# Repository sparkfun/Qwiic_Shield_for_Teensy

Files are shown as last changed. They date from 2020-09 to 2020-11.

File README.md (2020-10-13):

SparkFun Qwiic Shield for Teensy 
========================================

SparkFun Qwiic Shield for Teensy

[SparkFun Qwiic Shield for Teensy (DEV-17119)](https://www.sparkfun.com/products/17119)

The SparkFun Qwiic Shield for Teensy connects the I<sup>2</sup>C bus on a Teensy footprint (Teensy 4, 3.2, LC) to four Qwiic connectors as well as a "PROG" button in parallel with the Program button on the Teensy development board for easy access. The shield comes with the [Teensy Header Kit](https://www.sparkfun.com/products/13925) to solder to the shield for connection to the Teensy.

Repository Contents
-------------------

* **/Documentation** - Board schematic (PDF) and dimensions (PNG & PDF)
* **/Hardware** - Eagle design files (.brd, .sch)

Documentation
--------------
* **[Hookup Guide](https://learn.sparkfun.com/tutorials/sparkfun-qwiic-shield-for-teensy-hookup-guide)** - Basic hookup guide for the SparkFun Qwiic Shield for Teensy

Version History
---------------
* **[DEV-17119](https://www.sparkfun.com/products/17119)** - Initial release.

License Information
-------------------

This product is _**open source**_! 

Please review the LICENSE.md file for license information. 

If you have any questions or concerns on licensing, please contact technical support on our [SparkFun forums](https://forum.sparkfun.com/viewforum.php?f=152).

Distributed as-is; no warranty is given.

- Your friends at SparkFun.

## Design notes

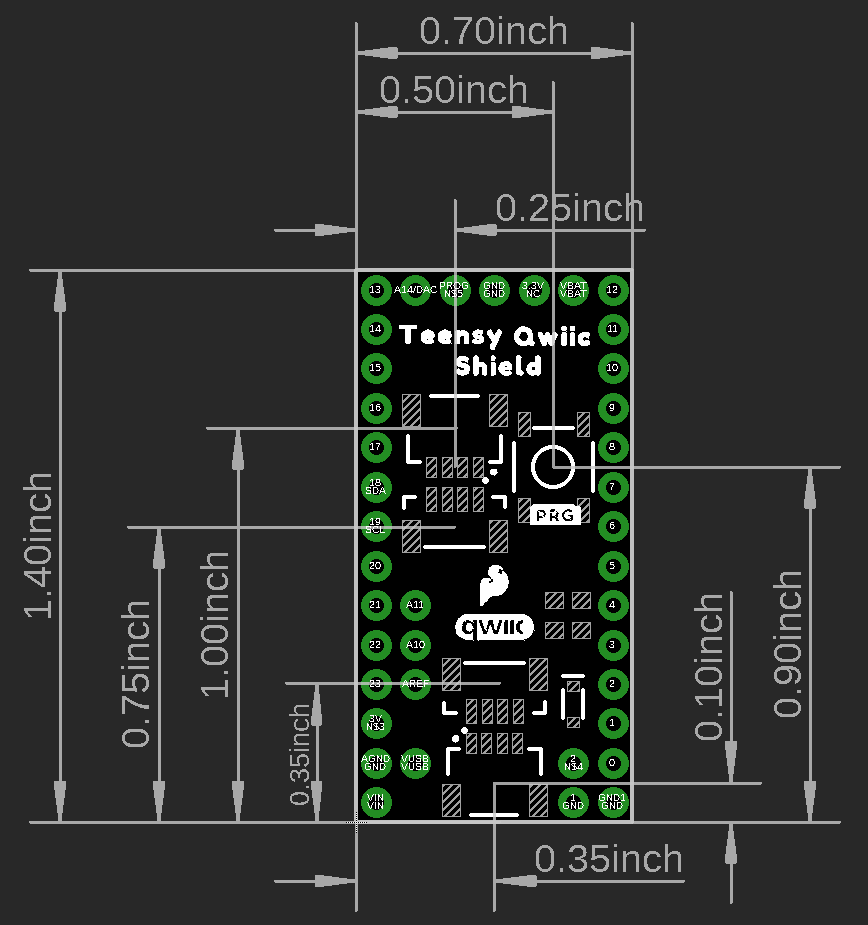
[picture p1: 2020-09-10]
Documents/Qwiic_Shield_for_Teensy_Dimensions.png

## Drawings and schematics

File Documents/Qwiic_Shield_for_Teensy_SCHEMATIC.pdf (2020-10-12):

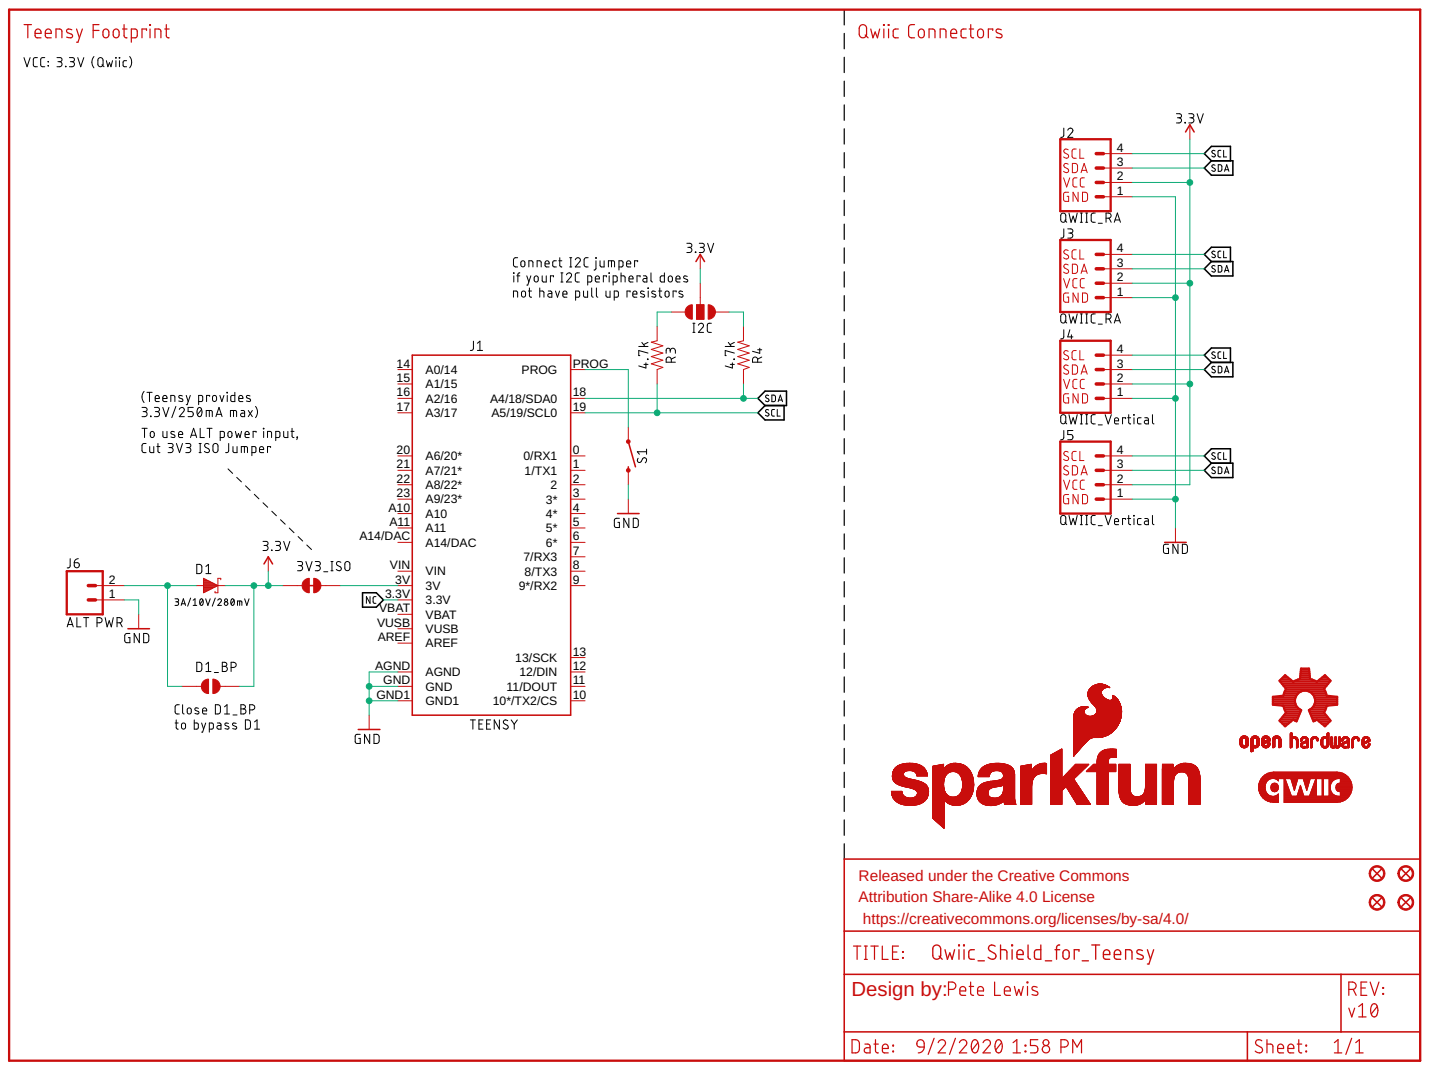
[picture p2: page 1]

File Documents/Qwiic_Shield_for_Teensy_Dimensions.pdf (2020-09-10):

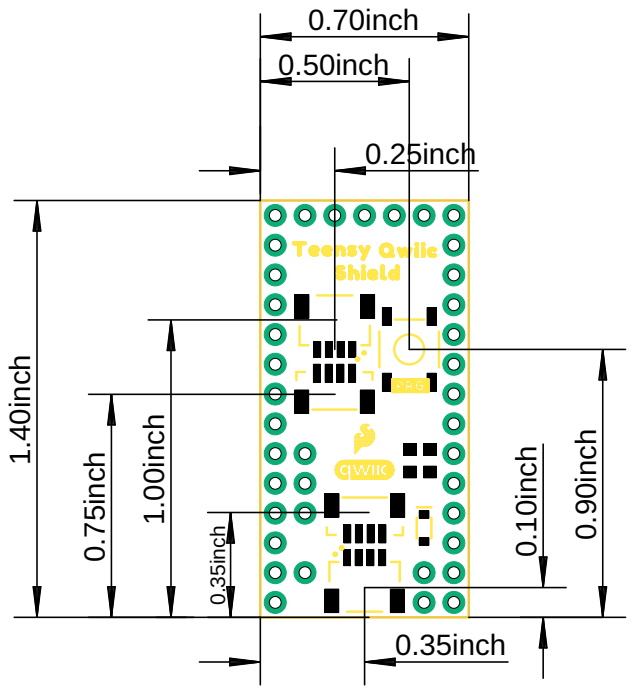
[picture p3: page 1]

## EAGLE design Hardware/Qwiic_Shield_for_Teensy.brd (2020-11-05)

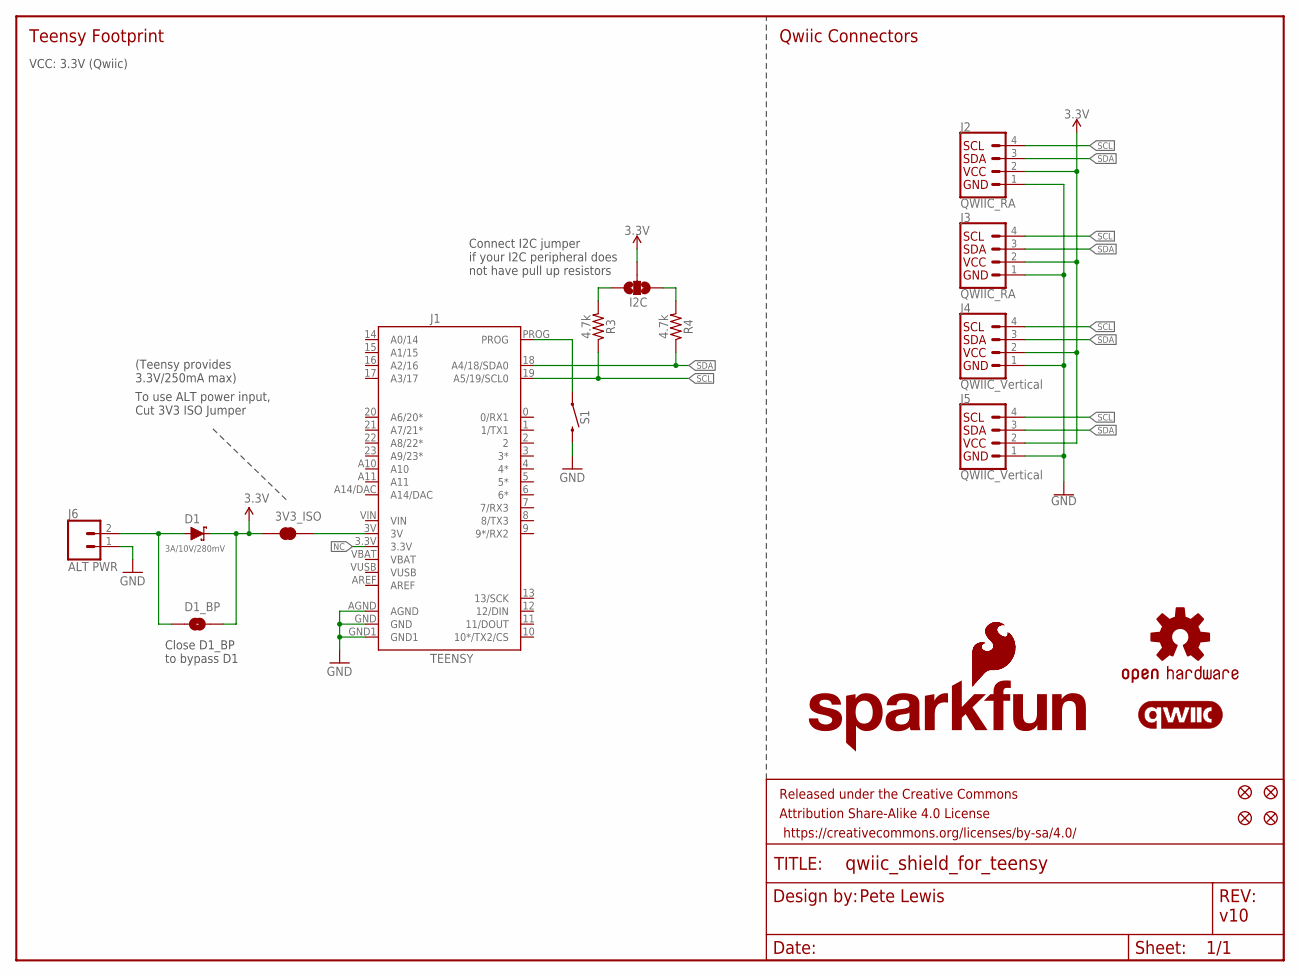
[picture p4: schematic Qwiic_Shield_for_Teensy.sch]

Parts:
3V3_ISO: JUMPER-SMT_2_NC_TRACE_SILK; SMT-JUMPER_2_NC_TRACE_SILK
D1: 3A/10V/280mV; SOD-323
D1_BP: JUMPER-SMT_2_NO_SILK; SMT-JUMPER_2_NO_SILK
FD1, FD2, FD3, FD4: FIDUCIAL1X2; FIDUCIAL-1X2
FRAME1: FRAME-LETTER; CREATIVE_COMMONS
I2C: JUMPER-SMT_3_NO_SILK; SMT-JUMPER_3_NO_SILK
J1: TEENSY; TEENSY_NOSILK
J2, J3: QWIIC_RA; JST04_1MM_RA
J4, J5: QWIIC_Vertical; JST04_1MM_VERT
J6: ALT PWR; 1X02_NO_SILK
LOGO1: SFE_LOGO_NAME_FLAME.1_INCH; SFE_LOGO_NAME_FLAME_.1
LOGO2: SFE_LOGO_FLAME.1_INCH; SFE_LOGO_FLAME_.1
LOGO3: OSHW-LOGOS; OSHW-LOGO-S
LOGO4: QWIIC_LOGO_5MM; QWIIC_5MM
R3, R4: 4.7k; 0603
S1: SMD_5.2MM; TACTILE_SWITCH_SMD_5.2MM

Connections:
3.3V: 3V3_ISO.1, D1.C, D1_BP.2, I2C.2, J2.2, J3.2, J4.2, J5.2
GND: J1.AGND, J1.GND, J1.GND1, J2.1, J3.1, J4.1, J5.1, J6.1, S1.3 (2)
unnamed: I2C.3, R4.2
unnamed: I2C.1, R3.2
unnamed: 3V3_ISO.2, J1.3V
unnamed: D1.A, D1_BP.1, J6.2
unnamed: J1.PROG, S1.1
NC: J1.3.3V
SCL: J1.19 (A5/19/SCL0), J2.4, J3.4, J4.4, J5.4, R3.1
SDA: J1.18 (A4/18/SDA0), J2.3, J3.3, J4.3, J5.3, R4.1
VBAT: J1.VBAT
VIN: J1.VIN
VUSB: J1.VUSB

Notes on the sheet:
Pete Lewis
v10
Teensy Footprint
Qwiic Connectors
VCC: 3.3V (Qwiic)
(Teensy provides 3.3V/250mA max)
Connect I2C jumper if your I2C peripheral does not have pull up resistors
To use ALT power input, Cut 3V3 ISO Jumper
Close D1_BP to bypass D1

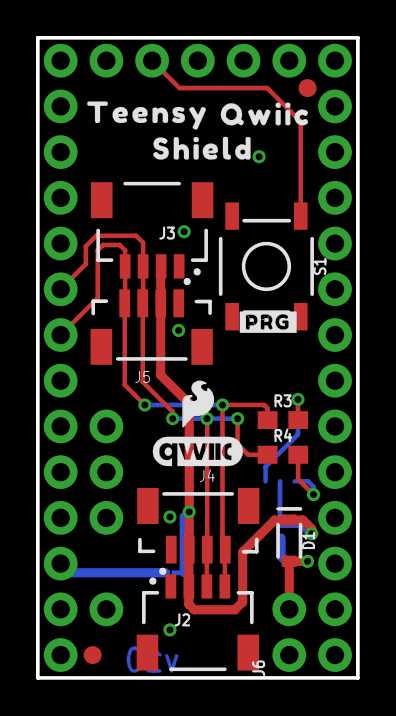
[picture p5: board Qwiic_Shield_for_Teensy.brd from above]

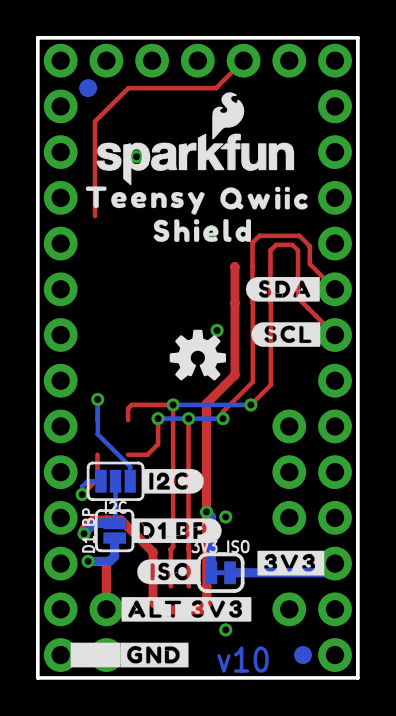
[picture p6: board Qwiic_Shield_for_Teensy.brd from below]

Board: 2 copper layers, 17.8 x 35.6 mm, 38 parts (18 on the bottom side), 9 nets.

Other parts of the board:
U$1: #I2C#0
U$2, U$13: TEENSY0
U$3: 3V36
U$4: #D1_BP#0
U$5: #ALT_3V3#0
U$6: #PRG#0
U$7: #GND#0
U$8, U$12: SHIELD0
U$9, U$11: QWIIC0
U$10: #ISO#0
U$15: #3V3#0
U$18: #SDA#0
U$19: #SCL#0

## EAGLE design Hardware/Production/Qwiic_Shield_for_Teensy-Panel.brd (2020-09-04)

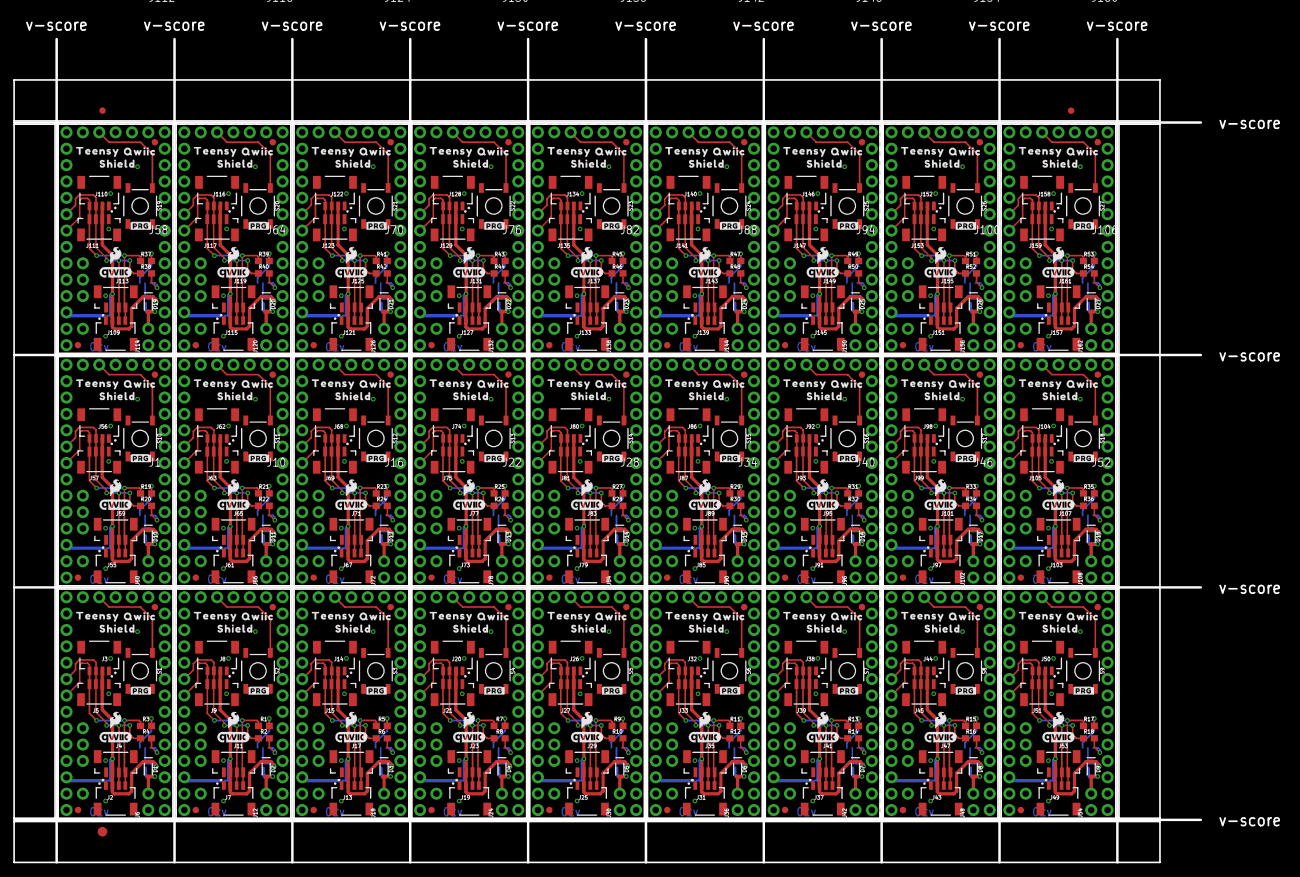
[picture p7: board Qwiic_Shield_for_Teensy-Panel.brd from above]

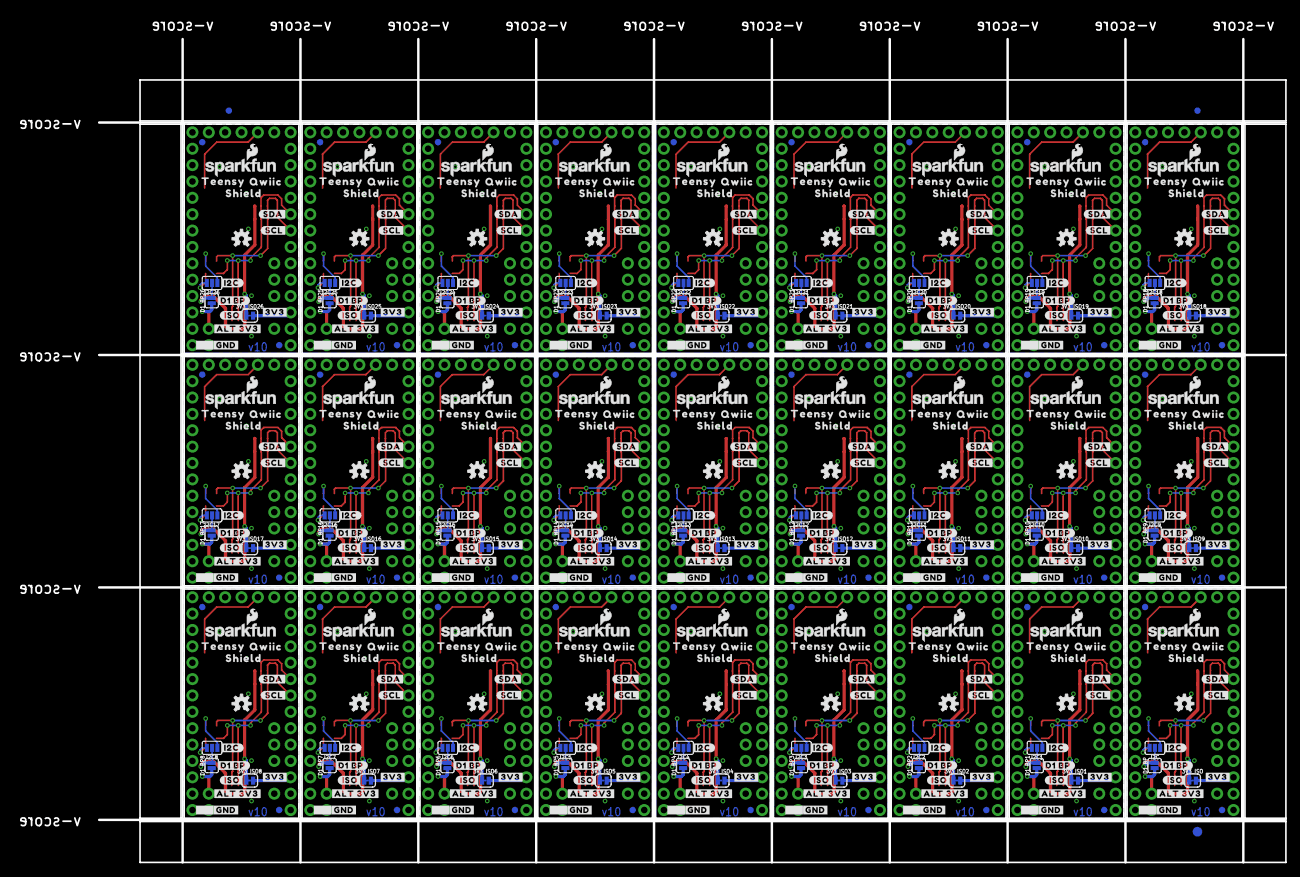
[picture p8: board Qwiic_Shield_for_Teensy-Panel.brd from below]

Board: 2 copper layers, 184.2 x 127.8 mm, 1005 parts (489 on the bottom side), 243 nets.

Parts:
3V3_ISO, 3V3_ISO1, 3V3_ISO2, 3V3_ISO3, 3V3_ISO4, 3V3_ISO5, 3V3_ISO6, 3V3_ISO7, 3V3_ISO8, 3V3_ISO9, 3V3_ISO10, 3V3_ISO11, 3V3_ISO12, 3V3_ISO13, 3V3_ISO14, 3V3_ISO15, 3V3_ISO16, 3V3_ISO17, 3V3_ISO18, 3V3_ISO19, 3V3_ISO20, 3V3_ISO21, 3V3_ISO22, 3V3_ISO23, 3V3_ISO24, 3V3_ISO25, 3V3_ISO26: SMT-JUMPER_2_NC_TRACE_SILK
D1, D2, D3, D4, D5, D6, D7, D8, D9, D10, D11, D12, D13, D14, D15, D16, D17, D18, D19, D20, D21, D22, D23, D24, D25, D26, D27: 3A/10V/280mV; SOD-323
D1_BP, D1_BP1, D1_BP2, D1_BP3, D1_BP4, D1_BP5, D1_BP6, D1_BP7, D1_BP8, D1_BP9, D1_BP10, D1_BP11, D1_BP12, D1_BP13, D1_BP14, D1_BP15, D1_BP16, D1_BP17, D1_BP18, D1_BP19, D1_BP20, D1_BP21, D1_BP22, D1_BP23, D1_BP24, D1_BP25, D1_BP26: SMT-JUMPER_2_NO_SILK
E$1, E$2, E$3, E$4: FIDUCIAL-1X2
E$5, E$6: FIDUCIAL-1.5X3
FD1, FD2, FD3, FD4, FD5, FD6, FD7, FD8, FD9, FD10, FD11, FD12, FD13, FD14, FD15, FD16, FD17, FD18, FD19, FD20, FD21, FD22, FD23, FD24, FD25, FD26, FD27, FD28, FD29, FD30, FD31, FD32, FD33, FD34, FD35, FD36, FD37, FD38, FD39, FD40, FD41, FD42, FD43, FD44, FD45, FD46, FD47, FD48, FD49, FD50, FD51, FD52, FD53, FD54, FD55, FD56, FD57, FD58, FD59, FD60, FD61, FD62, FD63, FD64, FD65, FD66, FD67, FD68, FD69, FD70, FD71, FD72, FD73, FD74, FD75, FD76, FD77, FD78, FD79, FD80, FD81, FD82, FD83, FD84, FD85, FD86, FD87, FD88, FD89, FD90, FD91, FD92, FD93, FD94, FD95, FD96, FD97, FD98, FD99, FD100, FD101, FD102, FD103, FD104, FD105, FD106, FD107, FD108: FIDUCIAL1X2; FIDUCIAL-1X2
I2C, I2C1, I2C2, I2C3, I2C4, I2C5, I2C6, I2C7, I2C8, I2C9, I2C10, I2C11, I2C12, I2C13, I2C14, I2C15, I2C16, I2C17, I2C18, I2C19, I2C20, I2C21, I2C22, I2C23, I2C24, I2C25, I2C26: JUMPER-SMT_3_NO_SILK; SMT-JUMPER_3_NO_SILK
J1, J10, J16, J22, J28, J34, J40, J46, J52, J58, J64, J70, J76, J82, J88, J94, J100, J106, J112, J118, J124, J130, J136, J142, J148, J154, J160: TEENSY; TEENSY_NOSILK
J2, J3, J7, J8, J13, J14, J19, J20, J25, J26, J31, J32, J37, J38, J43, J44, J49, J50, J55, J56, J61, J62, J67, J68, J73, J74, J79, J80, J85, J86, J91, J92, J97, J98, J103, J104, J109, J110, J115, J116, J121, J122, J127, J128, J133, J134, J139, J140, J145, J146, J151, J152, J157, J158: QWIIC_RA; JST04_1MM_RA
J4, J5, J9, J11, J15, J17, J21, J23, J27, J29, J33, J35, J39, J41, J45, J47, J51, J53, J57, J59, J63, J65, J69, J71, J75, J77, J81, J83, J87, J89, J93, J95, J99, J101, J105, J107, J111, J113, J117, J119, J123, J125, J129, J131, J135, J137, J141, J143, J147, J149, J153, J155, J159, J161: QWIIC_Vertical; JST04_1MM_VERT
J6, J12, J18, J24, J30, J36, J42, J48, J54, J60, J66, J72, J78, J84, J90, J96, J102, J108, J114, J120, J126, J132, J138, J144, J150, J156, J162: ALT PWR; 1X02_NO_SILK
LOGO1, LOGO5, LOGO9, LOGO13, LOGO17, LOGO21, LOGO25, LOGO29, LOGO33, LOGO37, LOGO41, LOGO45, LOGO49, LOGO53, LOGO57, LOGO61, LOGO65, LOGO69, LOGO73, LOGO77, LOGO81, LOGO85, LOGO89, LOGO93, LOGO97, LOGO101, LOGO105: SFE_LOGO_NAME_FLAME.1_INCH; SFE_LOGO_NAME_FLAME_.1
LOGO2, LOGO8, LOGO12, LOGO16, LOGO20, LOGO24, LOGO28, LOGO32, LOGO36, LOGO40, LOGO44, LOGO48, LOGO52, LOGO56, LOGO60, LOGO64, LOGO68, LOGO72, LOGO76, LOGO80, LOGO84, LOGO88, LOGO92, LOGO96, LOGO100, LOGO104, LOGO108: SFE_LOGO_FLAME.1_INCH; SFE_LOGO_FLAME_.1
LOGO3, LOGO6, LOGO10, LOGO14, LOGO18, LOGO22, LOGO26, LOGO30, LOGO34, LOGO38, LOGO42, LOGO46, LOGO50, LOGO54, LOGO58, LOGO62, LOGO66, LOGO70, LOGO74, LOGO78, LOGO82, LOGO86, LOGO90, LOGO94, LOGO98, LOGO102, LOGO106: OSHW-LOGOS; OSHW-LOGO-S
LOGO4, LOGO7, LOGO11, LOGO15, LOGO19, LOGO23, LOGO27, LOGO31, LOGO35, LOGO39, LOGO43, LOGO47, LOGO51, LOGO55, LOGO59, LOGO63, LOGO67, LOGO71, LOGO75, LOGO79, LOGO83, LOGO87, LOGO91, LOGO95, LOGO99, LOGO103, LOGO107: QWIIC_LOGO_5MM; QWIIC_5MM
R1, R2, R3, R4, R5, R6, R7, R8, R9, R10, R11, R12, R13, R14, R15, R16, R17, R18, R19, R20, R21, R22, R23, R24, R25, R26, R27, R28, R29, R30, R31, R32, R33, R34, R35, R36, R37, R38, R39, R40, R41, R42, R43, R44, R45, R46, R47, R48, R49, R50, R51, R52, R53, R54: 4.7k; 0603
S1, S2, S3, S4, S5, S6, S7, S8, S9, S10, S11, S12, S13, S14, S15, S16, S17, S18, S19, S20, S21, S22, S23, S24, S25, S26, S27: SMD_5.2MM; TACTILE_SWITCH_SMD_5.2MM
U$1, U$22, U$38, U$54, U$70, U$86, U$102, U$118, U$134, U$150, U$166, U$182, U$198, U$214, U$230, U$246, U$262, U$278, U$294, U$310, U$326, U$342, U$358, U$374, U$390, U$406, U$422: #I2C#0
U$2, U$13, U$16, U$30, U$34, U$46, U$50, U$62, U$66, U$78, U$82, U$94, U$98, U$110, U$114, U$126, U$130, U$142, U$146, U$158, U$162, U$174, U$178, U$190, U$194, U$206, U$210, U$222, U$226, U$238, U$242, U$254, U$258, U$270, U$274, U$286, U$290, U$302, U$306, U$318, U$322, U$334, U$338, U$350, U$354, U$366, U$370, U$382, U$386, U$398, U$402, U$414, U$418, U$430: TEENSY0
U$3, U$14, U$33, U$49, U$65, U$81, U$97, U$113, U$129, U$145, U$161, U$177, U$193, U$209, U$225, U$241, U$257, U$273, U$289, U$305, U$321, U$337, U$353, U$369, U$385, U$401, U$417: 3V36
U$4, U$23, U$39, U$55, U$71, U$87, U$103, U$119, U$135, U$151, U$167, U$183, U$199, U$215, U$231, U$247, U$263, U$279, U$295, U$311, U$327, U$343, U$359, U$375, U$391, U$407, U$423: #D1_BP#0
U$5, U$24, U$40, U$56, U$72, U$88, U$104, U$120, U$136, U$152, U$168, U$184, U$200, U$216, U$232, U$248, U$264, U$280, U$296, U$312, U$328, U$344, U$360, U$376, U$392, U$408, U$424: #ALT_3V3#0
U$6, U$28, U$44, U$60, U$76, U$92, U$108, U$124, U$140, U$156, U$172, U$188, U$204, U$220, U$236, U$252, U$268, U$284, U$300, U$316, U$332, U$348, U$364, U$380, U$396, U$412, U$428: #PRG#0
U$7, U$25, U$41, U$57, U$73, U$89, U$105, U$121, U$137, U$153, U$169, U$185, U$201, U$217, U$233, U$249, U$265, U$281, U$297, U$313, U$329, U$345, U$361, U$377, U$393, U$409, U$425: #GND#0
U$8, U$12, U$26, U$32, U$42, U$48, U$58, U$64, U$74, U$80, U$90, U$96, U$106, U$112, U$122, U$128, U$138, U$144, U$154, U$160, U$170, U$176, U$186, U$192, U$202, U$208, U$218, U$224, U$234, U$240, U$250, U$256, U$266, U$272, U$282, U$288, U$298, U$304, U$314, U$320, U$330, U$336, U$346, U$352, U$362, U$368, U$378, U$384, U$394, U$400, U$410, U$416, U$426, U$432: SHIELD0
U$9, U$11, U$27, U$31, U$43, U$47, U$59, U$63, U$75, U$79, U$91, U$95, U$107, U$111, U$123, U$127, U$139, U$143, U$155, U$159, U$171, U$175, U$187, U$191, U$203, U$207, U$219, U$223, U$235, U$239, U$251, U$255, U$267, U$271, U$283, U$287, U$299, U$303, U$315, U$319, U$331, U$335, U$347, U$351, U$363, U$367, U$379, U$383, U$395, U$399, U$411, U$415, U$427, U$431: QWIIC0
U$10, U$29, U$45, U$61, U$77, U$93, U$109, U$125, U$141, U$157, U$173, U$189, U$205, U$221, U$237, U$253, U$269, U$285, U$301, U$317, U$333, U$349, U$365, U$381, U$397, U$413, U$429: #ISO#0
U$15, U$17, U$35, U$51, U$67, U$83, U$99, U$115, U$131, U$147, U$163, U$179, U$195, U$211, U$227, U$243, U$259, U$275, U$291, U$307, U$323, U$339, U$355, U$371, U$387, U$403, U$419: #3V3#0
U$18, U$20, U$36, U$52, U$68, U$84, U$100, U$116, U$132, U$148, U$164, U$180, U$196, U$212, U$228, U$244, U$260, U$276, U$292, U$308, U$324, U$340, U$356, U$372, U$388, U$404, U$420: #SDA#0
U$19, U$21, U$37, U$53, U$69, U$85, U$101, U$117, U$133, U$149, U$165, U$181, U$197, U$213, U$229, U$245, U$261, U$277, U$293, U$309, U$325, U$341, U$357, U$373, U$389, U$405, U$421: #SCL#0

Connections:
3.3V: 3V3_ISO.1, D1.C, D1_BP.2, I2C.2, J2.2, J3.2, J4.2, J5.2
3.3V1: 3V3_ISO1.1, D1_BP1.2, D2.C, I2C1.2, J7.2, J8.2, J9.2, J11.2
3.3V2: 3V3_ISO2.1, D1_BP2.2, D3.C, I2C2.2, J13.2, J14.2, J15.2, J17.2
3.3V3: 3V3_ISO3.1, D1_BP3.2, D4.C, I2C3.2, J19.2, J20.2, J21.2, J23.2
3.3V4: 3V3_ISO4.1, D1_BP4.2, D5.C, I2C4.2, J25.2, J26.2, J27.2, J29.2
3.3V5: 3V3_ISO5.1, D1_BP5.2, D6.C, I2C5.2, J31.2, J32.2, J33.2, J35.2
3.3V6: 3V3_ISO6.1, D1_BP6.2, D7.C, I2C6.2, J37.2, J38.2, J39.2, J41.2
3.3V7: 3V3_ISO7.1, D1_BP7.2, D8.C, I2C7.2, J43.2, J44.2, J45.2, J47.2
3.3V8: 3V3_ISO8.1, D1_BP8.2, D9.C, I2C8.2, J49.2, J50.2, J51.2, J53.2
3.3V9: 3V3_ISO9.1, D1_BP9.2, D10.C, I2C9.2, J55.2, J56.2, J57.2, J59.2
3.3V10: 3V3_ISO10.1, D1_BP10.2, D11.C, I2C10.2, J61.2, J62.2, J63.2, J65.2
3.3V11: 3V3_ISO11.1, D1_BP11.2, D12.C, I2C11.2, J67.2, J68.2, J69.2, J71.2
3.3V12: 3V3_ISO12.1, D1_BP12.2, D13.C, I2C12.2, J73.2, J74.2, J75.2, J77.2
3.3V13: 3V3_ISO13.1, D1_BP13.2, D14.C, I2C13.2, J79.2, J80.2, J81.2, J83.2
3.3V14: 3V3_ISO14.1, D1_BP14.2, D15.C, I2C14.2, J85.2, J86.2, J87.2, J89.2
3.3V15: 3V3_ISO15.1, D1_BP15.2, D16.C, I2C15.2, J91.2, J92.2, J93.2, J95.2
3.3V16: 3V3_ISO16.1, D1_BP16.2, D17.C, I2C16.2, J97.2, J98.2, J99.2, J101.2
3.3V17: 3V3_ISO17.1, D1_BP17.2, D18.C, I2C17.2, J103.2, J104.2, J105.2, J107.2
3.3V18: 3V3_ISO18.1, D1_BP18.2, D19.C, I2C18.2, J109.2, J110.2, J111.2, J113.2
3.3V19: 3V3_ISO19.1, D1_BP19.2, D20.C, I2C19.2, J115.2, J116.2, J117.2, J119.2
3.3V20: 3V3_ISO20.1, D1_BP20.2, D21.C, I2C20.2, J121.2, J122.2, J123.2, J125.2
3.3V21: 3V3_ISO21.1, D1_BP21.2, D22.C, I2C21.2, J127.2, J128.2, J129.2, J131.2
3.3V22: 3V3_ISO22.1, D1_BP22.2, D23.C, I2C22.2, J133.2, J134.2, J135.2, J137.2
3.3V23: 3V3_ISO23.1, D1_BP23.2, D24.C, I2C23.2, J139.2, J140.2, J141.2, J143.2
3.3V24: 3V3_ISO24.1, D1_BP24.2, D25.C, I2C24.2, J145.2, J146.2, J147.2, J149.2
3.3V25: 3V3_ISO25.1, D1_BP25.2, D26.C, I2C25.2, J151.2, J152.2, J153.2, J155.2
3.3V26: 3V3_ISO26.1, D1_BP26.2, D27.C, I2C26.2, J157.2, J158.2, J159.2, J161.2
GND: J1.AGND, J1.GND, J1.GND1, J2.1, J3.1, J4.1, J5.1, J6.1, S1.3
GND1: J7.1, J8.1, J9.1, J10.AGND, J10.GND, J10.GND1, J11.1, J12.1, S2.3
GND2: J13.1, J14.1, J15.1, J16.AGND, J16.GND, J16.GND1, J17.1, J18.1, S3.3
GND3: J19.1, J20.1, J21.1, J22.AGND, J22.GND, J22.GND1, J23.1, J24.1, S4.3
GND4: J25.1, J26.1, J27.1, J28.AGND, J28.GND, J28.GND1, J29.1, J30.1, S5.3
GND5: J31.1, J32.1, J33.1, J34.AGND, J34.GND, J34.GND1, J35.1, J36.1, S6.3
GND6: J37.1, J38.1, J39.1, J40.AGND, J40.GND, J40.GND1, J41.1, J42.1, S7.3
GND7: J43.1, J44.1, J45.1, J46.AGND, J46.GND, J46.GND1, J47.1, J48.1, S8.3
GND8: J49.1, J50.1, J51.1, J52.AGND, J52.GND, J52.GND1, J53.1, J54.1, S9.3
GND9: J55.1, J56.1, J57.1, J58.AGND, J58.GND, J58.GND1, J59.1, J60.1, S10.3
GND10: J61.1, J62.1, J63.1, J64.AGND, J64.GND, J64.GND1, J65.1, J66.1, S11.3
GND11: J67.1, J68.1, J69.1, J70.AGND, J70.GND, J70.GND1, J71.1, J72.1, S12.3
GND12: J73.1, J74.1, J75.1, J76.AGND, J76.GND, J76.GND1, J77.1, J78.1, S13.3
GND13: J79.1, J80.1, J81.1, J82.AGND, J82.GND, J82.GND1, J83.1, J84.1, S14.3
GND14: J85.1, J86.1, J87.1, J88.AGND, J88.GND, J88.GND1, J89.1, J90.1, S15.3
GND15: J91.1, J92.1, J93.1, J94.AGND, J94.GND, J94.GND1, J95.1, J96.1, S16.3
GND16: J97.1, J98.1, J99.1, J100.AGND, J100.GND, J100.GND1, J101.1, J102.1, S17.3
GND17: J103.1, J104.1, J105.1, J106.AGND, J106.GND, J106.GND1, J107.1, J108.1, S18.3
GND18: J109.1, J110.1, J111.1, J112.AGND, J112.GND, J112.GND1, J113.1, J114.1, S19.3
GND19: J115.1, J116.1, J117.1, J118.AGND, J118.GND, J118.GND1, J119.1, J120.1, S20.3
GND20: J121.1, J122.1, J123.1, J124.AGND, J124.GND, J124.GND1, J125.1, J126.1, S21.3
GND21: J127.1, J128.1, J129.1, J130.AGND, J130.GND, J130.GND1, J131.1, J132.1, S22.3
GND22: J133.1, J134.1, J135.1, J136.AGND, J136.GND, J136.GND1, J137.1, J138.1, S23.3
GND23: J139.1, J140.1, J141.1, J142.AGND, J142.GND, J142.GND1, J143.1, J144.1, S24.3
GND24: J145.1, J146.1, J147.1, J148.AGND, J148.GND, J148.GND1, J149.1, J150.1, S25.3
GND25: J151.1, J152.1, J153.1, J154.AGND, J154.GND, J154.GND1, J155.1, J156.1, S26.3
GND26: J157.1, J158.1, J159.1, J160.AGND, J160.GND, J160.GND1, J161.1, J162.1, S27.3
unnamed: I2C.3, R4.2
unnamed: I2C.1, R3.2
unnamed: 3V3_ISO.2, J1.3V
unnamed: D1.A, D1_BP.1, J6.2
unnamed: J1.PROG, S1.1
unnamed: I2C1.3, R2.2
unnamed: I2C1.1, R1.2
unnamed: D1_BP1.1, D2.A, J12.2
unnamed: J10.PROG, S2.1
unnamed: 3V3_ISO1.2, J10.3V
unnamed: I2C2.3, R6.2
unnamed: I2C2.1, R5.2
unnamed: D1_BP2.1, D3.A, J18.2
unnamed: J16.PROG, S3.1
unnamed: 3V3_ISO2.2, J16.3V
unnamed: I2C3.3, R8.2
unnamed: I2C3.1, R7.2
unnamed: D1_BP3.1, D4.A, J24.2
unnamed: J22.PROG, S4.1
unnamed: 3V3_ISO3.2, J22.3V
unnamed: I2C4.3, R10.2
unnamed: I2C4.1, R9.2
unnamed: D1_BP4.1, D5.A, J30.2
unnamed: J28.PROG, S5.1
unnamed: 3V3_ISO4.2, J28.3V
unnamed: I2C5.3, R12.2
unnamed: I2C5.1, R11.2
unnamed: D1_BP5.1, D6.A, J36.2
unnamed: J34.PROG, S6.1
unnamed: 3V3_ISO5.2, J34.3V
unnamed: I2C6.3, R14.2
unnamed: I2C6.1, R13.2
unnamed: D1_BP6.1, D7.A, J42.2
unnamed: J40.PROG, S7.1
unnamed: 3V3_ISO6.2, J40.3V
unnamed: I2C7.3, R16.2
unnamed: I2C7.1, R15.2
unnamed: D1_BP7.1, D8.A, J48.2
unnamed: J46.PROG, S8.1
unnamed: 3V3_ISO7.2, J46.3V
unnamed: I2C8.3, R18.2
unnamed: I2C8.1, R17.2
unnamed: D1_BP8.1, D9.A, J54.2
unnamed: J52.PROG, S9.1
unnamed: 3V3_ISO8.2, J52.3V
unnamed: I2C9.3, R20.2
unnamed: I2C9.1, R19.2
unnamed: D1_BP9.1, D10.A, J60.2
unnamed: J58.PROG, S10.1
unnamed: 3V3_ISO9.2, J58.3V
unnamed: I2C10.3, R22.2
unnamed: I2C10.1, R21.2
unnamed: D1_BP10.1, D11.A, J66.2
unnamed: J64.PROG, S11.1
unnamed: 3V3_ISO10.2, J64.3V
unnamed: I2C11.3, R24.2
unnamed: I2C11.1, R23.2
unnamed: D1_BP11.1, D12.A, J72.2
unnamed: J70.PROG, S12.1
unnamed: 3V3_ISO11.2, J70.3V
unnamed: I2C12.3, R26.2
unnamed: I2C12.1, R25.2
unnamed: D1_BP12.1, D13.A, J78.2
unnamed: J76.PROG, S13.1
unnamed: 3V3_ISO12.2, J76.3V
unnamed: I2C13.3, R28.2
unnamed: I2C13.1, R27.2
unnamed: D1_BP13.1, D14.A, J84.2
unnamed: J82.PROG, S14.1
unnamed: 3V3_ISO13.2, J82.3V
unnamed: I2C14.3, R30.2
unnamed: I2C14.1, R29.2
unnamed: D1_BP14.1, D15.A, J90.2
unnamed: J88.PROG, S15.1
unnamed: 3V3_ISO14.2, J88.3V
unnamed: I2C15.3, R32.2
unnamed: I2C15.1, R31.2
unnamed: D1_BP15.1, D16.A, J96.2
unnamed: J94.PROG, S16.1
unnamed: 3V3_ISO15.2, J94.3V
unnamed: I2C16.3, R34.2
unnamed: I2C16.1, R33.2
unnamed: D1_BP16.1, D17.A, J102.2
unnamed: J100.PROG, S17.1
unnamed: 3V3_ISO16.2, J100.3V
unnamed: I2C17.3, R36.2
unnamed: I2C17.1, R35.2
unnamed: D1_BP17.1, D18.A, J108.2
unnamed: J106.PROG, S18.1
unnamed: 3V3_ISO17.2, J106.3V
unnamed: I2C18.3, R38.2
unnamed: I2C18.1, R37.2
unnamed: D1_BP18.1, D19.A, J114.2
unnamed: J112.PROG, S19.1
unnamed: 3V3_ISO18.2, J112.3V
unnamed: I2C19.3, R40.2
unnamed: I2C19.1, R39.2
unnamed: D1_BP19.1, D20.A, J120.2
unnamed: J118.PROG, S20.1
unnamed: 3V3_ISO19.2, J118.3V
unnamed: I2C20.3, R42.2
unnamed: I2C20.1, R41.2
unnamed: D1_BP20.1, D21.A, J126.2
unnamed: J124.PROG, S21.1
unnamed: 3V3_ISO20.2, J124.3V
unnamed: I2C21.3, R44.2
unnamed: I2C21.1, R43.2
unnamed: D1_BP21.1, D22.A, J132.2
unnamed: J130.PROG, S22.1
unnamed: 3V3_ISO21.2, J130.3V
unnamed: I2C22.3, R46.2
unnamed: I2C22.1, R45.2
unnamed: D1_BP22.1, D23.A, J138.2
unnamed: J136.PROG, S23.1
unnamed: 3V3_ISO22.2, J136.3V
unnamed: I2C23.3, R48.2
unnamed: I2C23.1, R47.2
unnamed: D1_BP23.1, D24.A, J144.2
unnamed: J142.PROG, S24.1
unnamed: 3V3_ISO23.2, J142.3V
unnamed: I2C24.3, R50.2
unnamed: I2C24.1, R49.2
unnamed: D1_BP24.1, D25.A, J150.2
unnamed: J148.PROG, S25.1
unnamed: 3V3_ISO24.2, J148.3V
unnamed: I2C25.3, R52.2
unnamed: I2C25.1, R51.2
unnamed: D1_BP25.1, D26.A, J156.2
unnamed: J154.PROG, S26.1
unnamed: 3V3_ISO25.2, J154.3V
unnamed: I2C26.3, R54.2
unnamed: I2C26.1, R53.2
unnamed: D1_BP26.1, D27.A, J162.2
unnamed: J160.PROG, S27.1
unnamed: 3V3_ISO26.2, J160.3V
SCL: J1.19, J2.4, J3.4, J4.4, J5.4, R3.1
SCL1: J7.4, J8.4, J9.4, J10.19, J11.4, R1.1
SCL2: J13.4, J14.4, J15.4, J16.19, J17.4, R5.1
SCL3: J19.4, J20.4, J21.4, J22.19, J23.4, R7.1
SCL4: J25.4, J26.4, J27.4, J28.19, J29.4, R9.1
SCL5: J31.4, J32.4, J33.4, J34.19, J35.4, R11.1
SCL6: J37.4, J38.4, J39.4, J40.19, J41.4, R13.1
SCL7: J43.4, J44.4, J45.4, J46.19, J47.4, R15.1
SCL8: J49.4, J50.4, J51.4, J52.19, J53.4, R17.1
SCL9: J55.4, J56.4, J57.4, J58.19, J59.4, R19.1
SCL10: J61.4, J62.4, J63.4, J64.19, J65.4, R21.1
SCL11: J67.4, J68.4, J69.4, J70.19, J71.4, R23.1
SCL12: J73.4, J74.4, J75.4, J76.19, J77.4, R25.1
SCL13: J79.4, J80.4, J81.4, J82.19, J83.4, R27.1
SCL14: J85.4, J86.4, J87.4, J88.19, J89.4, R29.1
SCL15: J91.4, J92.4, J93.4, J94.19, J95.4, R31.1
SCL16: J97.4, J98.4, J99.4, J100.19, J101.4, R33.1
SCL17: J103.4, J104.4, J105.4, J106.19, J107.4, R35.1
SCL18: J109.4, J110.4, J111.4, J112.19, J113.4, R37.1
SCL19: J115.4, J116.4, J117.4, J118.19, J119.4, R39.1
SCL20: J121.4, J122.4, J123.4, J124.19, J125.4, R41.1
SCL21: J127.4, J128.4, J129.4, J130.19, J131.4, R43.1
SCL22: J133.4, J134.4, J135.4, J136.19, J137.4, R45.1
SCL23: J139.4, J140.4, J141.4, J142.19, J143.4, R47.1
SCL24: J145.4, J146.4, J147.4, J148.19, J149.4, R49.1
SCL25: J151.4, J152.4, J153.4, J154.19, J155.4, R51.1
SCL26: J157.4, J158.4, J159.4, J160.19, J161.4, R53.1
SDA: J1.18, J2.3, J3.3, J4.3, J5.3, R4.1
SDA1: J7.3, J8.3, J9.3, J10.18, J11.3, R2.1
SDA2: J13.3, J14.3, J15.3, J16.18, J17.3, R6.1
SDA3: J19.3, J20.3, J21.3, J22.18, J23.3, R8.1
SDA4: J25.3, J26.3, J27.3, J28.18, J29.3, R10.1
SDA5: J31.3, J32.3, J33.3, J34.18, J35.3, R12.1
SDA6: J37.3, J38.3, J39.3, J40.18, J41.3, R14.1
SDA7: J43.3, J44.3, J45.3, J46.18, J47.3, R16.1
SDA8: J49.3, J50.3, J51.3, J52.18, J53.3, R18.1
SDA9: J55.3, J56.3, J57.3, J58.18, J59.3, R20.1
SDA10: J61.3, J62.3, J63.3, J64.18, J65.3, R22.1
SDA11: J67.3, J68.3, J69.3, J70.18, J71.3, R24.1
SDA12: J73.3, J74.3, J75.3, J76.18, J77.3, R26.1
SDA13: J79.3, J80.3, J81.3, J82.18, J83.3, R28.1
SDA14: J85.3, J86.3, J87.3, J88.18, J89.3, R30.1
SDA15: J91.3, J92.3, J93.3, J94.18, J95.3, R32.1
SDA16: J97.3, J98.3, J99.3, J100.18, J101.3, R34.1
SDA17: J103.3, J104.3, J105.3, J106.18, J107.3, R36.1
SDA18: J109.3, J110.3, J111.3, J112.18, J113.3, R38.1
SDA19: J115.3, J116.3, J117.3, J118.18, J119.3, R40.1
SDA20: J121.3, J122.3, J123.3, J124.18, J125.3, R42.1
SDA21: J127.3, J128.3, J129.3, J130.18, J131.3, R44.1
SDA22: J133.3, J134.3, J135.3, J136.18, J137.3, R46.1
SDA23: J139.3, J140.3, J141.3, J142.18, J143.3, R48.1
SDA24: J145.3, J146.3, J147.3, J148.18, J149.3, R50.1
SDA25: J151.3, J152.3, J153.3, J154.18, J155.3, R52.1
SDA26: J157.3, J158.3, J159.3, J160.18, J161.3, R54.1

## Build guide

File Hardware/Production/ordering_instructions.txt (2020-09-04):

panel size, 178x115mm
PCB thickness, 1.6mm
number of layers, 2
soldermask color, Red
silkscreen color, White
oz copper, 1oz
finish, HASL lead free
stencils, top
pcs per panel, 27
min trace width, 0.2540mm / 0.0100in
min drill size, 0.3810mm / 0.0150in

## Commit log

2020-08-20 ready for routing
    [Qwiic_Shield_for_Teensy.brd, Qwiic_Shield_for_Teensy.sch]
2020-08-24 Routing done
    -added diode on ALT 3V3 input
    -added PRG button for easier access to programming button
    -added prototyping area (with vscore) to extend this to also fit longer teensy board form factors
    [Qwiic_Shield_for_Teensy.brd, Qwiic_Shield_for_Teensy.sch]
2020-08-24 fixed tiny airwire
    [Qwiic_Shield_for_Teensy.brd]
2020-08-24 added measures
    [Qwiic_Shield_for_Teensy.brd]
2020-08-24 Teensy FP library update
    [Qwiic_Shield_for_Teensy.brd, Qwiic_Shield_for_Teensy.sch]
2020-08-25 DRC approvals, label adjustments
    -bumped GND pour isolates to 0.008 inch. This allows AREF pin to still get flowed gnd.
    -approved DRC errors about dimension on vscore line
    -fixed some angled traces.
    -removed some trace stubs
    -rotated SDA and SCL to match orientation of other labels
    -ensures all labels were size 0.04
    [Qwiic_Shield_for_Teensy.brd]
2020-08-25 checklist run pre group review
    -sch fonts to vector
    -via nudges to clear silk
    [Qwiic_Shield_for_Teensy.brd, Qwiic_Shield_for_Teensy.sch]
2020-08-31 Post group review changes - short version
    -"slave" terminology needs to be updated to "I2C peripheral"
    -Moving to two separate products. One short and one long. Resolves the prog button access pin difference. no vscores.
    -Switch up qwiic connector positions so that the north RA connector doesn't conflict with the prog button.
    -3.3V power should come from the PTH header pin on the side (not the middle row).
    -Added teensy qwiic shield product name to bottom silk
    [Qwiic_Shield_for_Teensy.brd, Qwiic_Shield_for_Teensy.sch]
2020-08-31 teensy long started
    library work and part placement mostly done. ready for routing.
    [Qwiic_Shield_for_Teensy_Long.brd, Qwiic_Shield_for_Teensy_Long.sch]
2020-09-01 Long version routed
    [Qwiic_Shield_for_Teensy_Long.brd, Qwiic_Shield_for_Teensy_Long.sch]
2020-09-01 Moving to "extended" product name
    -Eagle file name change (and sub-folder)
    -added silk to extended version
    [Qwiic_Shield_for_Teensy_Extended.brd, Qwiic_Shield_for_Teensy_Extended.sch]
2020-09-02 Library updates, name prefix fix, measures update
    [Qwiic_Shield_for_Teensy.brd, Qwiic_Shield_for_Teensy.sch, Qwiic_Shield_for_Teensy_Extended.brd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]
2020-09-02 separating repo into "normal" and extended versions
    [Qwiic_Shield_for_Teensy_Extended.brd, Qwiic_Shield_for_Teensy_Extended.sch]
2020-09-02 checklist run post design review
    -approved DRC overlap and clearance errors.
    -one small trace nudge to remove one extra unecessary kink
    -part name text adjustments for assembly sheet
    [Qwiic_Shield_for_Teensy.brd, Qwiic_Shield_for_Teensy.sch]
2020-09-03 measures correction
    -added x measure for bottom centered qwiic connector
    [Qwiic_Shield_for_Teensy.brd]
2020-09-04 production panel v10
    [Qwiic_Shield_for_Teensy-Panel.GBL, Qwiic_Shield_for_Teensy-Panel.GBO, Qwiic_Shield_for_Teensy-Panel.GBP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]
2020-09-04 added panel dimemsions x and y to panel brd file
    [Qwiic_Shield_for_Teensy-Panel.brd]
2020-11-05 Migrating teensy part to SparkFun-Boards.lbr
    -migrated teensy device from private mini library into public SparkFun-Boards.lbr
    -replaced part
    -deleted mini library in this repo
    [Qwiic_Shield_for_Teensy.brd, Qwiic_Shield_for_Teensy.sch]

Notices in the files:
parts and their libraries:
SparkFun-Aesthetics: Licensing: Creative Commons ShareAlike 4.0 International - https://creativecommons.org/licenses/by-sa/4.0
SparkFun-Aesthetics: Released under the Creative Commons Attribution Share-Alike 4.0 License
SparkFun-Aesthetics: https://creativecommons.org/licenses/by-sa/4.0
